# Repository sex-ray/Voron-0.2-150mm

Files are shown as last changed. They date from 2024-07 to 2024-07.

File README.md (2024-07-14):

Voron 0.2 3D打印机的150mm修改版，原版是XYZ轴的尺寸均为120mm，由于尺寸相对较小，因此我增加了XY轴的尺寸到150mm，Z轴高度未变。
其中硬件修改了以下部分:

1. 型材 与XY轴相关的型材了均增加了30mm 
2. 线轨  修改后的线轨参数为 3根180mm和2根150mm
3. 面板 分别修改了平台面板，电机面板和中间面板的长度及孔距
4. 打印件 修改了热床前端支架、裙边和线轨固定条模型的尺寸

修改后的模型外观延续了原版的设计

其他硬件和打孔位置均未更改，安装流程和原版也没有任何区别。
软件方面只需要在Klipper中修改printer配置文件中的一些尺寸参数

提供了修改后的模型文件、型材参数、及材料清单的，
其中也包含了基于必趣SKR PICO的配置文件作为参考。
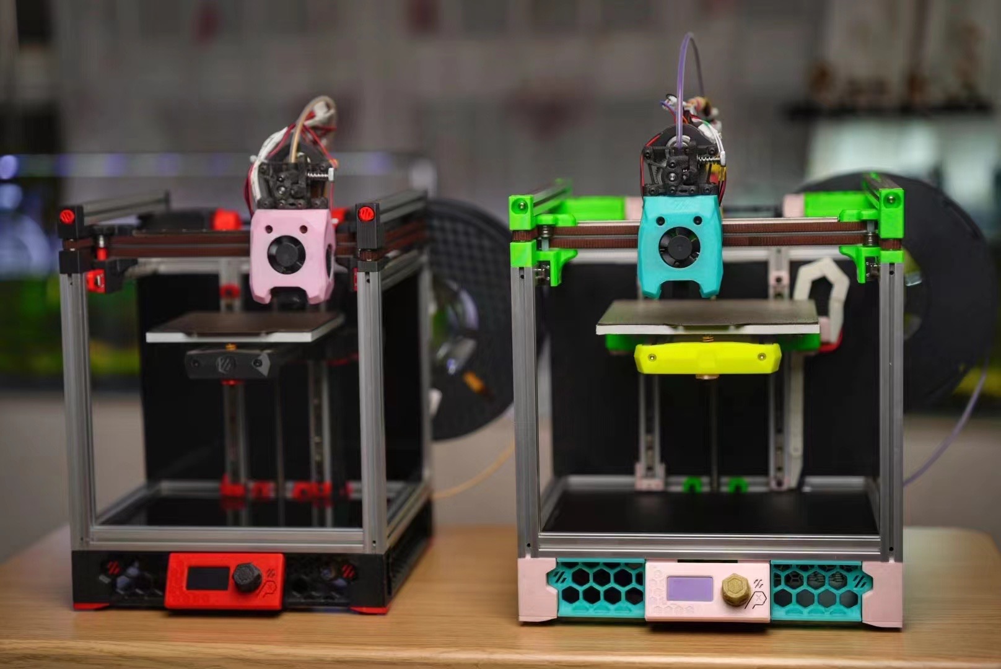
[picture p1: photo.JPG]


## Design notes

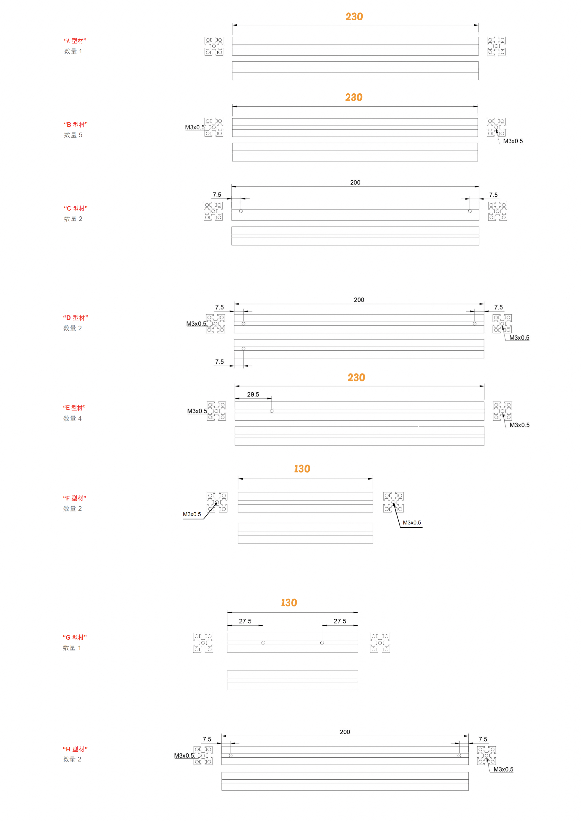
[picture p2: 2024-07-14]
型材尺寸及打孔图.jpg

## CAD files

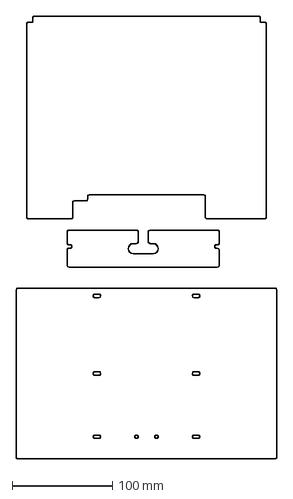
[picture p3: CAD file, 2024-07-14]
Panel 150.dxf
260.0 x 441.3 mm

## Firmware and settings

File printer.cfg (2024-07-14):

[include mainsail.cfg]
[include led_effects.cfg]
[virtual_sdcard]
path: /home/pi/printer_data/gcodes
on_error_gcode: CANCEL_PRINT


[gcode_macro CANCEL_PRINT]
description: Cancel the actual running print
rename_existing: CANCEL_PRINT_BASE
gcode:
  G1 E-5 F300
  G0 X140 Y140  Z50 F2000
  M84
  TURN_OFF_HEATERS
  CANCEL_PRINT_BASE

############################################
#M109#
############################################
[gcode_macro M109]
rename_existing: M99109
gcode:
    #Parameters
    {% set s = params.S|float %}
    
    M104 {% for p in params %}{'%s%s' % (p, params[p])}{% endfor %}  ; Set hotend temp
    {% if s != 0 %}
        TEMPERATURE_WAIT SENSOR=extruder MINIMUM={s} MAXIMUM={s+1}   ; Wait for hotend temp (within 1 degree)
    {% endif %}
    
# This file contains common pin mappings for the BIGTREETECH SKR Pico V1.0
# To use this config, the firmware should be compiled for the RP2040 with
# USB communication.

# The "make flash" command does not work on the SKR Pico V1.0. Instead,
# after running "make", copy the generated "out/klipper.uf2" file
# to the mass storage device in RP2040 boot mode

## Voron Design VORON 0.2 SKR Pico V1.0 config

## *** THINGS TO CHANGE/CHECK: ***
## MCU path                                                                     [mcu] section
## Z and Extruder motor currents                                                [tmc2209 stepper_*] sections. Uncomment the stepper motor you have
## Full steps per rotation for Extruder                                         [extruder] section
## Thermistor types                                                             [extruder] and [heater_bed] sections - See https://www.klipper3d.org/Config_Reference.html#common-thermistors for common thermistor types
## Motor currents                                                               [extruder] [stepper] and [_HOME_X/Y] macro sections
## PID tune                                                                     [extruder] and [heater_bed] sections
## Fine tune E steps                                                            [extruder] section
## For more info                                                                check https://docs.vorondesign.com/build/startup/#v0

[mcu]
#####################################################################
# Obtain definition by "ls -l /dev/serial/by-id/"
#####################################################################
#serial: /dev/serial/by-id/usb-Klipper_rp2040_REPLACE_WITH_YOUR_VALUE
serial: /dev/ttyS5 											# for UART connection 用于UART连接
restart_method: command

######################################################################
# 树莓派 MCU温度显示
# ACCELEROMETER_QUERY 检查加速度传感器状态
# SHAPER_CALIBRATE 自动测试 Auto test
######################################################################
[temperature_sensor pico]
sensor_type: temperature_mcu
min_temp: 0
max_temp: 100

[temperature_sensor orange_pi]
sensor_type: temperature_host
min_temp: 0
max_temp: 100

######################################################################
# 共振补偿 
# ACCELEROMETER_QUERY 检查加速度传感器状态
# SHAPER_CALIBRATE 自动测试 Auto test
######################################################################

[mcu opi]
serial: /tmp/klipper_host_mcu

[adxl345]
cs_pin: opi:gpio72
spi_bus: spidev1.0

[resonance_tester]
accel_chip: adxl345
probe_points: 75,75,20                                                        # 更改为热床中心点，依次为x,y,z 
                                                                    #Adjust to the center of the heat bed,  x, y, and z

###################################################################
## 打印机限制
###################################################################

[printer]
kinematics: corexy
max_velocity: 500
max_accel: 10000
max_z_velocity: 20
max_z_accel: 50
square_corner_velocity: 6.0

#####################################################################
#      X/Y 电机设置
#####################################################################

[stepper_x]
step_pin: gpio11                                                 # X轴电机脉冲引脚设置
dir_pin: !gpio10                                                 # X轴电机运行引脚设置,方向按实际判断，加感叹号会让运行方向反转
enable_pin: !gpio12                                              # X轴电机使能引脚设置,使能引脚需要加感叹号，否者电机不工作
rotation_distance: 40                                            # 主动带轮周长mm（2GT-20T带轮40）
microsteps: 32                                                   # 电机细分设置，细分越高，质量越高，但主控负荷越大
full_steps_per_rotation: 200                                     # 电机单圈所需脉冲数（1.8度电机:200，0.9度电机:400）
endstop_pin: tmc2209_stepper_x:virtual_endstop                   # 无限位归零配置
position_endstop: 150                                            # 软限位最大行程 
position_max: 150                                                # 机械限位最大行程 
homing_speed: 40                                                 # 复位速度 无限位归零建议不要高于40
homing_retract_dist: 0                                           # 第一次触发复位开关之后的后退距离；无限位改为0
homing_positive_dir: true                                        # 复位方向（一般不需要改动）

[tmc2209 stepper_x]
uart_pin: gpio9
tx_pin: gpio8
uart_address: 0
interpolate: False                                                # 是否开启256微步插值（开启是True，关闭是False）
run_current: 1                                                    # 电机运行电流值（单位：mA）
sense_resistor: 0.110                                             # 驱动采样电阻不要改
stealthchop_threshold: 0                                          # 静音阀值（如果不需要静音，请将数值改为0）
diag_pin: ^gpio4    											  # 设置MCU引脚连接到TMC的DIAG引脚；无限位
driver_SGTHRS: 104				    				    	      # 无限位灵敏度 255是最敏感的值，0是最不敏感的值

[stepper_y]
step_pin: gpio6                                                  # Y轴电机脉冲引脚设置
dir_pin: !gpio5                                                   # Y轴电机运行引脚设置,方向按实际判断，加感叹号会让运行方向反转
enable_pin: !gpio7                                               # Y轴电机使能引脚设置,使能引脚需要加感叹号，否者电机不工作
rotation_distance: 40                                            # 主动带轮周长mm（2GT-20T带轮40）
microsteps: 32                                                   # 电机细分设置，细分越高，质量越高，但主控负荷越大
full_steps_per_rotation: 200                                     # 电机单圈所需脉冲数（1.8度电机:200，0.9度电机:400）
endstop_pin: tmc2209_stepper_y:virtual_endstop                   # 无限位归零配置
position_endstop: 150                                            # 软限位最大行程 
position_max: 150                                                # 机械限位最大行程 
homing_speed: 40                                                 # 复位速度 无限位归零建议不要高于40 
homing_retract_dist: 0                                           # 第一次触发复位开关之后的后退距离；无限位改为0
homing_positive_dir: true                                        # 复位方向（一般不需要改动）

[tmc2209 stepper_y]
uart_pin: gpio9
tx_pin: gpio8
uart_address: 2
interpolate: False                                               # 是否开启256微步插值（开启是True，关闭是False）
run_current: 0.8                                                 # 电机运行电流值（单位：mA）
sense_resistor: 0.110                                            # 驱动采样电阻不要改
stealthchop_threshold: 0                                         # 静音阀值（如果不需要静音，请将数值改为0）
diag_pin: ^gpio3    										     # 设置MCU引脚连接到TMC的DIAG引脚；无限位
driver_SGTHRS: 99   				    				   	     # 无限位灵敏度 255是最敏感的值，0是最不敏感的值

#####################################################################
#   Z 电机设置
#####################################################################
[stepper_z]
step_pin: gpio19		                       	                  #驱动步进脚
dir_pin: gpio28		                        	                  #驱动方向引脚，如果发现方向相反在前加！
enable_pin: !gpio2		                        	              #电机使能引脚，如果发现，未归位电机锁死，操作电机时不转并且此时电机没有锁死，在前面加！
rotation_distance: 8	                         	           	  ## 用于导程8丝杆
microsteps: 32			                         	           	  #步进电机使用的细分数
endstop_pin: ^gpio25	                      	              	  #引脚触发限位
position_max: 121		                             	          #可移动的最大值
position_min: -1.5 		                         	           	  #可移动的最小值
homing_speed: 20			                         	          #归位速度
homing_retract_dist: 3.0	                        	          #第一次碰到限位回缩距离
second_homing_speed: 3		                            	      #第二次去触发限位时候的速度


[tmc2209 stepper_z]
uart_pin: gpio9
tx_pin: gpio8
uart_address: 1
interpolate: False                                                # 是否开启256微步插值（开启是True，关闭是False）
run_current: 0.2                                                  # 电机运行电流值（单位：mA）
sense_resistor: 0.110                                             # 驱动采样电阻不要改
stealthchop_threshold: 0                                          # 静音阀值（如果不需要静音，请将数值改为0）

#####################################################################
#   挤出机
#####################################################################
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
